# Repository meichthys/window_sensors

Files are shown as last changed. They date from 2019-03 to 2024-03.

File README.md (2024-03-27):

# Incredibly Cheap Wireless Window/Door Sensors

## Overview

This project is intended to provide tools/code/documentation for creating and setting up very inexpensive window/door sensors. The project will not describe every detail in the process but it will point you to the needed links. The sensors are designed to work within the following parameters.

- Cost under $5 each
- Work seemlessly with home automation software
- Be easy to create and maintain
- Be wireless (Wifi & Battery powered)
- Have a usable battery lifespan (YMMV, but I currently have some sensors over 2 years old with the original battery!)

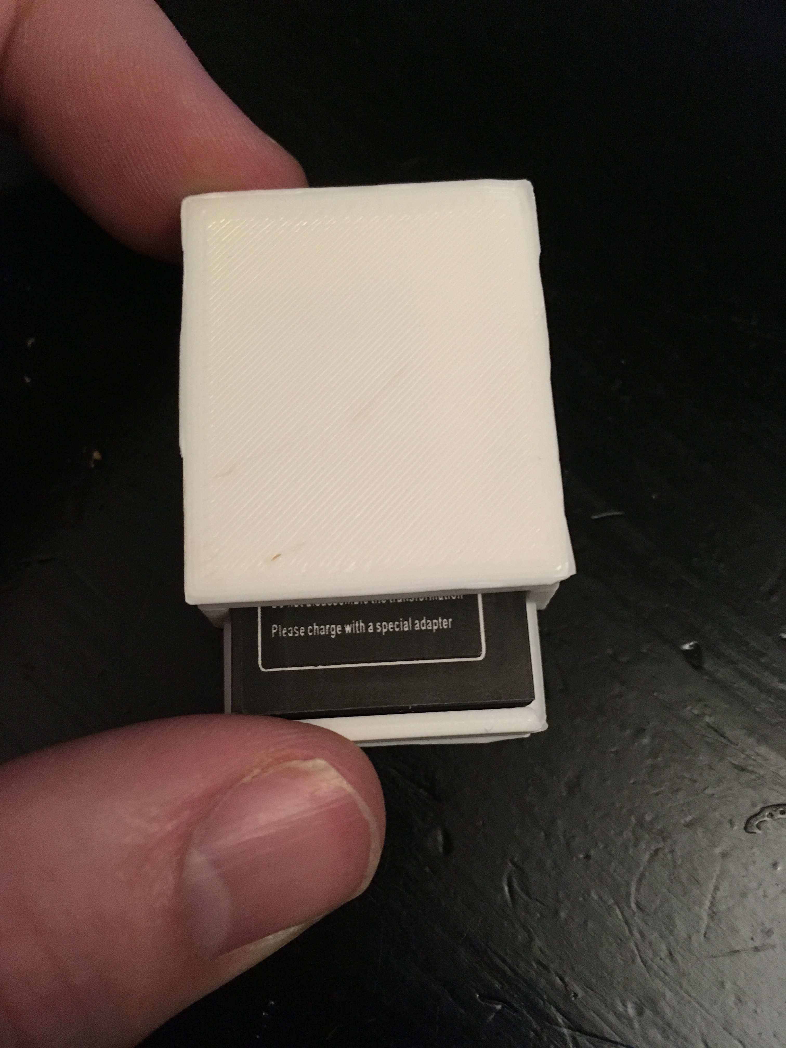
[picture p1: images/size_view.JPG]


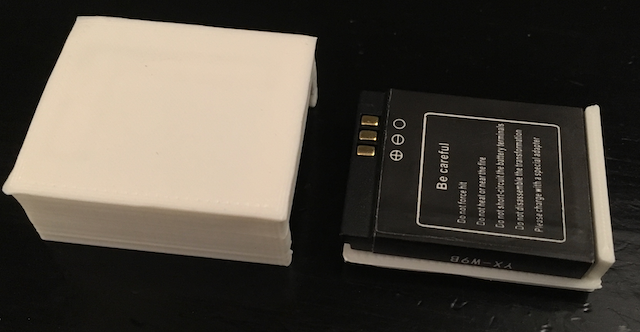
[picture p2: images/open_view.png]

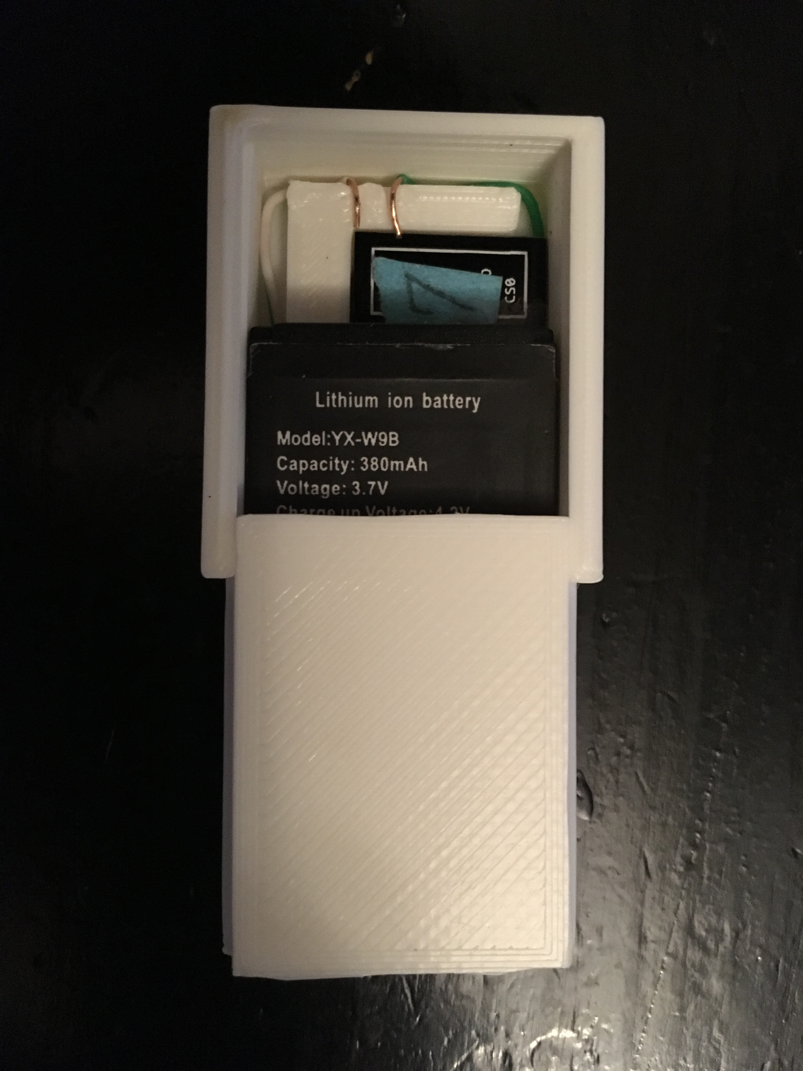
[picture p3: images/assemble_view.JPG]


## Supplies/Requirements

### Sensor Components

The following components are required to build a single sensor.

- x1 [ESP8266 12E](https://www.aliexpress.com/w/wholesale-ESP8266-ESP12F-Serial-WIFI-Model-ESP12E-Upgrade.html)
- x1 [Normally closed Reed Switch](https://www.aliexpress.com/w/wholesale-normally-closed-reed-switch-3-pin.html)
- x1 [3.7v YX-W9B Rechargable Battery](https://www.aliexpress.com/w/wholesale-palo-watch-battery-smart-dz09.html)
- x1 2" insulated small guage copper wire (The twisted pairs of a ethernet cable work perfectly)
- x1 [15x5x5mm Magnets](https://www.aliexpress.com/w/wholesale-15x5x5-magnet.html)

### Development Components

These following components can be purchased once and used to assemble any number of sensors:

- x1 [USB to TTL adapter](http://a.co/d/hhTu3ec) (Drivers can be found [here](http://www.prolific.com.tw/US/ShowProduct.aspx?pcid=41&showlevel=0041-0041))
- (Optional, but Highly Recommended) x1 [Breadboard kit](https://www.aliexpress.com/w/wholesale-breadboard-kit-mb102.html)
- (Optional, but Highly Recommended) x1 ESP to Breadboard Adapter ([Pin Headers](https://www.aliexpress.com/w/wholesale-1x40-single-row-pin-header.html), x2 [Adapter](https://www.aliexpress.com/w/wholesale-2.5%22-Inch-44-pin-to-3.5%22-Inch-40-pin-IDE-laptop.html))
    - The Pin Headers fit into the holes on the ESP12E chip
    - The Adapters connect the ESP to the breadboard without needing to solder anything!

### Software Components

- [ESPHomeFlasher](https://github.com/esphome/esphome-flasher/releases)
- [ESPHome](https://esphome.io)
- [Home Automation Software](https://www.home-assistant.io)

## Building & Testing

The general build process to build a sensor looks like:

1. [Flash your ESP8266 with the ESPHome firmware](#flash-esp8266-with-esphome-firmware)
2. [Setup ESPHome integration in Homeassistant](#homeassistant) or [Configure MQTT broker to receive signal from sensor](#mqtt)
3. Print the enclosure ([Bottom](enclosure/Bottom.stl),[Top](enclosure/Top.stl), [MagnetHolder](enclosure/MagnetHolder.stl))
4. [Assemble & test sensor](#assemble--test-sensor)
5. Repeat setps 1-4 for many more sensors!

### Flash ESP8266 with ESPHome firmware

ESPHome makes programming the esp microcontroller very easy - no Arduino, or sketch programming knowledge is needed. All the configuration is done via simple yaml configurations. We just need to simply follow the ESPHome documentation to assemble a configuration file that will notify our home automation software whenever the microcontroller powers on. To install ESPHome Firmware:

1. Follow the ESPHome [Getting Started walkthrough](https://esphome.io/guides/getting_started_hassio.html).
2. Once finished with the initial ESPHome wizard, download the base firmware from ESPHome by clicking on the three dot menu and choosing *compile*, then choosing *Download Binary* once compiling has finished. (We will update this fimware later with our own configuration)
3. Flash the ESPHome Binary to the ESP8266 chip using [ESPHomeFlasher](https://github.com/esphome/esphome-flasher/releases)
    - [Wire the ESP12E for flashing mode](http://cdn.srccodes.com/c/2017/02/57/6.png). (It is very helpful to use a breadboard along with the adapter mentioned above (See [image](images/esp8266_flash_wiring.png))
    - Download [ESPHomeFlasher](https://github.com/esphome/esphome-flasher/releases)
    - Flash the downloaded *.bin* firmware to the esp8266 chip using [ESPHomeFlasher](https://github.com/esphome/esphome-flasher/releases).
    - Use the ESPHome web interface to configure and re-flash the esp8266 chip wirelessly with either the [Homeassistant](esphome_homeassistant.yaml)(recommended) or [MQTT](esphome_mqtt.yaml) ESPHome config file containing the [HomeAssistant](###HomeAssistant)/[MQTT](###MQTT) configurations explained below. Be sure to update the sample config files to rename the sensor and replace any `<replace_me>` placeholders with your personal details.

## Setup ESPHome integration in Homeassistantor or configure MQTT broker to receive signal from sensor

### HomeAssistant (Recommended)

Using the sample [HomeAssistant ESPHome config file](esphome_homeassistant.yaml), the sensor will notify HomeAssistant that the sensor's state has changed. This will be done via the HomeAssistant api as defined in the config file: `api:`. To let HomeAssistant know about the sensor, [setup the ESPHome integration](https://my.home-assistant.io/redirect/config_flow_start?domain=esphome) in HomeAssistant using the ip address (or hostname) you updated in the [ESPHome config file](esphome_homeassistant.yaml) (leave the default port).
Note: When setting up the HomeAssistant ESPHome integration, the window senwor should be powered on!

### MQTT

If you are not using the recommended HomeAssistant configuration, you can setup this sensor to work with any MQTT broker. Using the sample [MQTT ESPHome config file](esphome_mqtt.yaml), the sensor will send an MQTT signal to a specific MQTT topic that is specified in the ESPHome configuration. In order for the sensor to be useful, you will need to configure an MQTT server (broker) to receive the message that will be sent by the sensor. HomeAssistant has a built-in MQTT server that is easy to configure and is the preferred MQTT broker that this project will use. Setup in HomeAssistant is simple:

1. [Setup Homeassistant](https://www.home-assistant.io/getting-started/) & enable the HASSIO [MQTT Add-On](https://www.home-assistant.io/addons/mosquitto/)
2. Test your MQTT broker by using an [MQTT client](https://www.hivemq.com/blog/seven-best-mqtt-client-tools/). From your client MQTT tool, you will just need to make sure you are publishing to the same topic you've specified in your homeassistant setup.

## Print Enclosure

You will need to 3D-Print or [have someone print the enclosure for you](https://lifehacker.com/five-best-3d-printing-services-1706410803). The enclosure consists of the following:

- [The Bottom](enclosure/Bottom.stl) (Holds the ESP8266 chip and the magnetically activated reed switch)
- [The Top](enclosure/Top.stl) (Seals the sensor & holds the battery in place)
- [The Magnet Holder](enclosure/MagnetHolder.stl) (Holds the magnets used to activate the sensor)

Note: If you would like to edit the design of the enclosure, open the [WindowSensorEnclosure.skp](enclosure/WindowSensorEnclosure.skp) file in [Sketchup](https://www.sketchup.com) and submit a pull request if you think the desing is worth sharing!

## Assemble & Test Sensor

Assemble the sensor by completing the following:

- Solder a jumper wire between the *EN* pin and the *VCC* pin on the esp8266
- Solder a jumper wire or bridge the *IO15* pin and the *GND* pin on the esp8266 (See [image](images/esp8266_pre_install.png))
- Solder one end of the reed switch to the *GND* pin of the esp8266
- Solder the copper wire to the *EN* or *VCC* pin of the esp8266
- Place the esp8266 in the bottom of the enclosure and bend the reed switch wire and the copper wire so that the ends sit in the grooves. (This requires a little patience to get the wires situated correctly, but once they are set, they shouln't need to be adjusted again.)
- Insert the battery and confirm that the esp8266 powers on. If it doesn't power on, re-check your wiring and battery voltage.
- Using Homeassistant or an MQTT Client, verify that the MQTT message is being sent on the topic you specified in the ESPHome config.
- (Optionally) Setup [automations](https://www.home-assistant.io/components/automation/) in HomeAssistant to your liking to trigger actions based upon sensor state. While you're at it setup iOS notifications to get notified of state changes on your iPhone and Apple Watch:

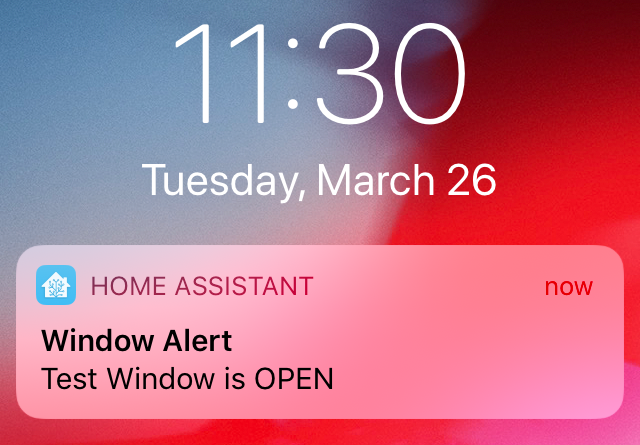
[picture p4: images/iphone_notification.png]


## Known Issues

- Battery life should last over 1 year on windows/doors that are not opened frequently (Some of my sensors lasted 3 years!), but windows/doors that are opened frequently will last significantly less time as WiFi consumes battery power
- This sensor is built to run in a powered-off state until the door/window is opened - this may result in an 'unavailable' voltage state in HomeAssistant while the sensor is powered off.

## Potential Improvements

- Ideally the sensor would be fall back to a [Deep Sleep mode](https://esphome.io/components/deep_sleep.html?highlight=sleep) instead of powering completely off.
    - This would speed up the sensor response times (They are currently about 2 seconds).
    - This would likely require a change in wiring/soldering
    - This may reduce battery life slightly.
- We need a 3D printed charging port for the batteries. I've currently just been throwing the batteries away since they are so cheap, but they should be re-chargable.
    - It is also possible to charge the batteries using aligator clips and a programable power supply (Do this at your own risk!).

## Credits & Inspiration

### ESPHome

[ESPHome](https://esphome.io) made the whole project incredibly easier and more enjoyable. I'm glad I found ESPHome while working on this project! Please check them out and support their work if you can.

### TheHookup

Original inspiration for this project came from [thehookup](https://github.com/thehookup/MQTT_Window_Sensors). His youtube videos below were helpful in visualizing how the sensor could work.
Wireless MQTT Window Sensors with the ESP-01: [Part 1](https://www.youtube.com/watch?v=BoYVr2UwWWg) & [Part 2](https://www.youtube.com/watch?v=2kLZ7DlP9KU)

## Contributions

Any pull requests and/or improvements would be greatly appreciated.

## License

[MIT Licnese](license.txt)

## Support

If you found this project helpful, please let me know by considering supporting me. This gives me an incentive to keep it up to date.
You can support me on Liberapay or Github Sponsors:

<a href="https://liberapay.com/meichthys/donate">Donate using Liberapay</a>

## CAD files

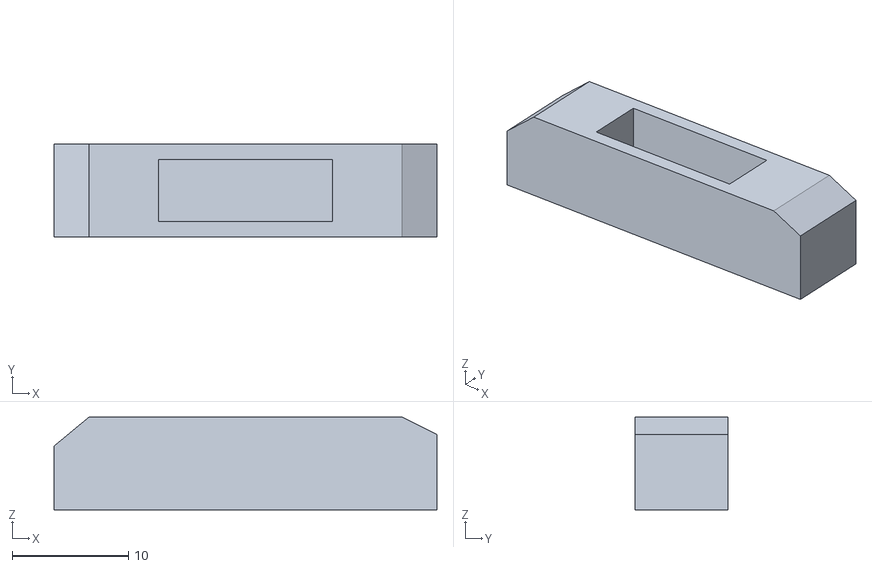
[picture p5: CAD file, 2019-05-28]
enclosure/MagnetHolder.stl
33.0 x 8.00 x 8.00

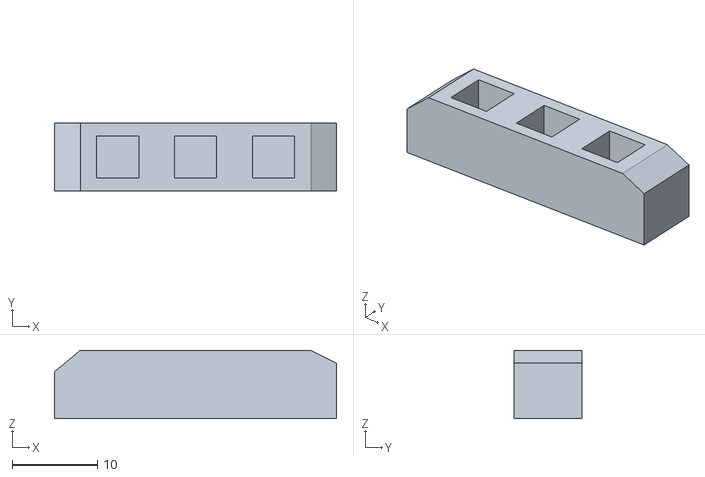
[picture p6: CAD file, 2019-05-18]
MagnetHolder.stl
33.0 x 8.00 x 8.00

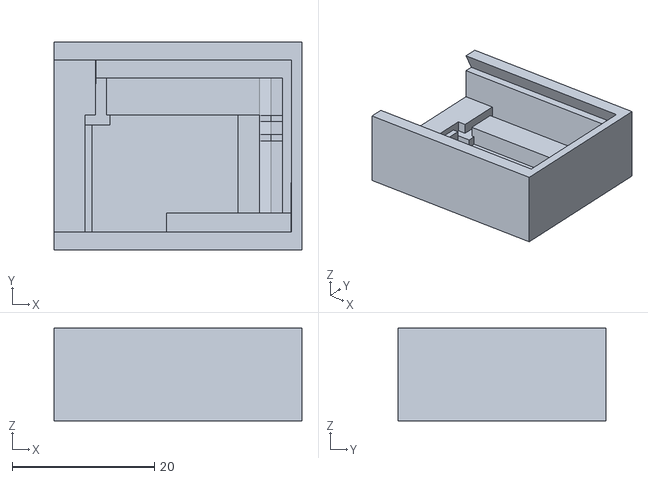
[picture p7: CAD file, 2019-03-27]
enclosure/Bottom.stl
34.9 x 29.2 x 13.0

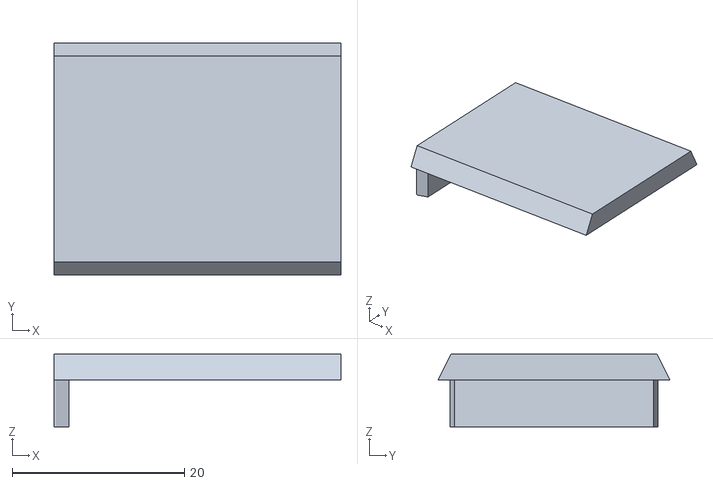
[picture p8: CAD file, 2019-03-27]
enclosure/Top.stl
33.3 x 27.0 x 8.45

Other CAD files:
enclosure/WindowSensorEnclosure.skp

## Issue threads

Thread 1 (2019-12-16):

How often can you open the window before recharge?

filipre, 2019-12-16:
Hi,

First of all, nice project!

According to your [Reddit post](https://www.reddit.com/r/homeassistant/comments/b5zpf0/insanely_cheap_diy_wireless_windowdoor_sensors/) you said that the sensor will last for about a year. However, I was wondering how long it will last in terms of "opening and closing" your window. The related [video](https://www.youtube.com/watch?v=BoYVr2UwWWg) said that the "3V Lithium CR2032 Batteries " will power the device for about 20 openings but you are using a 3.7V battery with higher capacity so I assume it will be a bit higher. Do you have some data on that?

Also, I was wondering whether there exists a better solution to make it last longer. In Germany, we open the windows at least once a day so recharging the battery every 15 - 20 days is quite a lot.

Best!

meichthys, 2019-12-16:
@filipre Thanks, As for the battery life, most of my windows are still on the second charge so it appears that i'm getting close to 6 months on a charge. That being said, i only open my windows about once a week, so in your use case you might get closer to 2 months, but that's just a guess.

On a side note, if you do decide to get the batteries that i linked to, they may slightly expand after a few months or after recharging. I used a very fine pin and pricked a very small hole in the very outside sheath to prevent the battery from bulging further (This only happened on a few of the batteries, so it could have just been a slight defect in manufacturing).

In the future i'd like to add to the project a small charging station for the batteries (Currently i just use aligator clips to charge them, but it would be nice to just have a small station that i can swap batteries in and out as needed.

filipre, 2019-12-16:
I see, thank you!

Closed 2019-12-16.

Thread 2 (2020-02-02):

Battery Life and Dual state.

puneit-hassio, 2020-02-02:
hello 👋 thanks for developing this great project. I have a question

How long does the battery last.
Also , can we not use SPDT reed switch which gives but normally open and normally closed states.

meichthys, 2020-02-05:
@puneit-hassio
So far the batteries seem to last about 5 months on a charge. I still have plans to add to this project by including a 3d printed charger for the batteries listed in the readme. Not sure when i'll get around to this though.

As for the reed switches, you should be able to use anything that results in a normally closed state so the battery doesn't drain. (Even if you put the device in deep-sleep mode, the battery will drain within a few days).

An alternate configuration would be to use a normally open reed switch and then place your magnet near the door stopper. (This wouldn't normally be optimal since the open door wouldn't always be in the perfect spot to trigger the reed switch.)

Ulrar, 2020-05-17:
Speaking of chargers, what do you use to charge these batteries ?

meichthys, 2020-05-17:
@Ulrar I use [this](https://www.amazon.com/dp/B00466PKE0/ref=cm_sw_r_cp_awdb_t1_9rtWEbD3DW83K) because I had it laying around, but any single cell lipo battery charger should work. I just clip the alligator clips on the positive and negative terminals. It works well, but I may improve the usability some by printing a battery charger port that we could use to “plug“ the batteries into for easier charging.

Closed 2020-02-05.

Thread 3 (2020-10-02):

Just a question

ClouDevelopment, 2020-10-02:
Love the project.

I am working on my first sensor, but was wondering how long the battery works before you need to recharge it?  Speaking of recharging the battery, do you have an easy way to do this already?

Thanks
-Steve

meichthys, 2020-10-02:
Hi Steve I think there was another issue where I answered some questions on battery life, but in general they seem to last about a year or so if the windows are not opened on a regular basis. If used on a door or something more regularly used, it will probably be a few months.

Because my batteries are mostly still good, I haven't designed a re-charging port yet, but I probably will at some point.

GeneArnold, 2021-01-08:
So are you soldering the battery directly to the chip? I was looking at your design and could not tell if you just lay the battery on top of the wires or solder them. Thank you.

meichthys, 2021-01-08:
The battery slides on top of the contact wires, so no soldering needed. The battery cover provides enough pressure to keep the battery connected. 👍

meichthys, 2021-01-08:
And for a battery update, I've had many of the sensors installed for over a year now and most of them are still on their first charge! I've replaced/recharged a few batteries that were installed on sensors that get used much more often.

meichthys, 2022-03-18:
The batteries finally died. So about two years on a new battery.

Closed 2022-03-18.

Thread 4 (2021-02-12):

Having battery alert

aliakbar-bsr, 2021-02-12:
Hi
Im interested in your code while it's esphome based
is there any way like the hookup to have alert on battery ending power to know that we have to replace it ?

meichthys, 2021-02-12:
@aliakbar-bsr Yes, there is a way to have a battery voltage level reported. Here's an example that replaces MQTT and uses the Home Assistant API to report the battery voltage as well as the sensor on/off status:

```
esphome:
  name: <name of device in esphome>
  platform: ESP8266
  board: esp12e

wifi:
  ssid: "Your Wifi Name here"
  password: "Your Wifi password here"
  fast_connect: true
  power_save_mode: high
# static ip is recommended to improve connection times
  manual_ip:
    static_ip: <static_ip_of_sensor>
    gateway: <gateway ip>
    subnet: 255.255.255.0
    dns1: <dns_server_ip>

binary_sensor:
  platform: status
  name: <name of on/off sensor>
  device_class: window

#  report battery voltage
sensor:
  platform: adc
  pin: VCC
  name: <name of voltage sensor>

# Enable logging
logger:

# Enable Home Assistant API
api:

# Enable over the air updates
ota:

```

Closed 2021-02-12.

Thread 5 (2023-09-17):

Broken Links

dskvr, 2023-09-17:
Parts list has broken list, adds quite a bit of friction for getting started.

1. 5mm magnet
2. ESP breadboard adapter

Generally wouldn't be a big deal but there's no information on magnet dimensions/shape anywhere, can't really tell from models and none of the photos show the magnet.

Thank you for this project, looks great!!

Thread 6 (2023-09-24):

Theoretical v2 with Integrated Charging Circuit (TP4056)

dskvr, 2023-09-24:
```
+5V
 |
[USB1]
 |
 |
[U1] TP4056
 |   |
 |   +-----> [BATT1] 3.7V LiPo
 |         |
 |         |
[U2] AMS1117-3.3
 |   |   |
 |   |   +----||---- GND   (C1: 10uF)
 |   |   |
 |   |   +----||---- GND   (C2: 0.1uF)
 |   |
 |   |
[U3] ESP8266MOD
 |   |   |
 |   |   +----/ /---- GND   (SW1: Reed Switch)
 |   |
 |   +---------||--------- (W1: Copper Wire/Antenna)
 |
 GND
```

Legend:

[USB1]: Micro USB for charging
[U1]: TP4056 Charger Module
[BATT1]: 3.7V LiPo Battery
[U2]: AMS1117-3.3 Voltage Regulator
[U3]: ESP8266MOD
||: Capacitor
/ /: Reed Switch

Weblist:

```
+5V
 |
[USB1]
 |
 |
[U1] TP4056
 |   |
 |   +-----> [BATT1] 3.7V LiPo
 |         |
 |         |
[U2] AMS1117-3.3
 |   |   |
 |   |   +----||---- GND   (C1: 10uF)
 |   |   |
 |   |   +----||---- GND   (C2: 0.1uF)
 |   |
 |   |
[U3] ESP8266MOD
 |   |   |
 |   |   +----/ /---- GND   (SW1: Reed Switch)
 |   |
 |   +---------||--------- (W1: Copper Wire/Antenna)
 |
 GND

```

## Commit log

2018-11-05 rename files
    [back.stl, front.stl, magnet.stl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]
2018-11-05 update sample config.yaml file
2019-03-27 add MagnetHolder.stl
    [MagnetHolder.stl]
2019-03-27 add magnet to needed hardware
2019-03-27 update battery link
2019-05-18 update magnet holder for stronger, easier magnets
    [MagnetHolder.stl]
2019-05-18 update skp file and move magnet holder file into correct directory
    [MagnetHolder.stl, WindowSensorEnclosure.skp]
2019-05-19 improve magnetic field distance of magnets
    [MagnetHolder.stl]
2019-05-28 More easily fit magnets
    [MagnetHolder.stl]
2021-10-13 Add note about battery life
2023-09-19 Updated Materials List links
    Made links generic search results since listings can come and go.
